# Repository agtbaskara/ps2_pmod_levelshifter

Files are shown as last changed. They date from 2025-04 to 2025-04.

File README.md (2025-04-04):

# PS/2 Pmod with Level Shifter

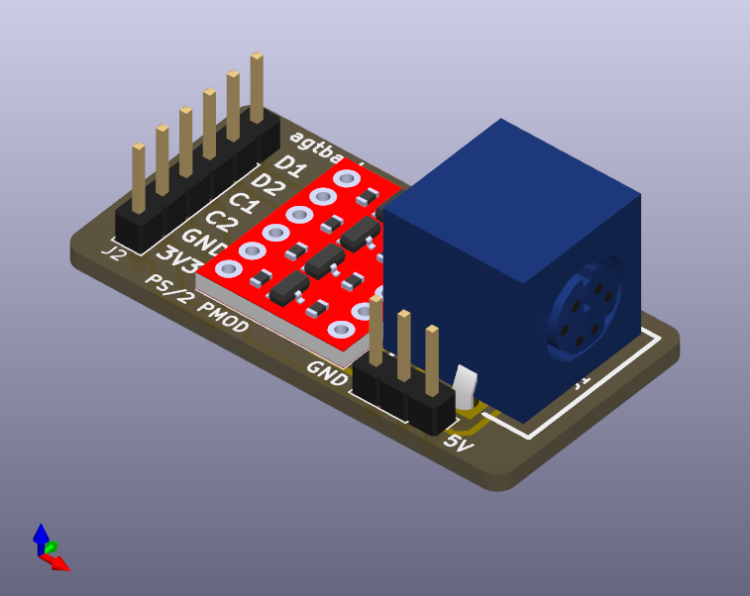
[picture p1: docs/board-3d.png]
Board 3D Render


An Open-Source PS/2 Pmod with Level Shifter to convert the PS/2 signal from 5V to 3.3V.

This board support either 3.3V to 5V step-up converter or external 5V input.

This board intended to use for FPGA projects.

# Schematic

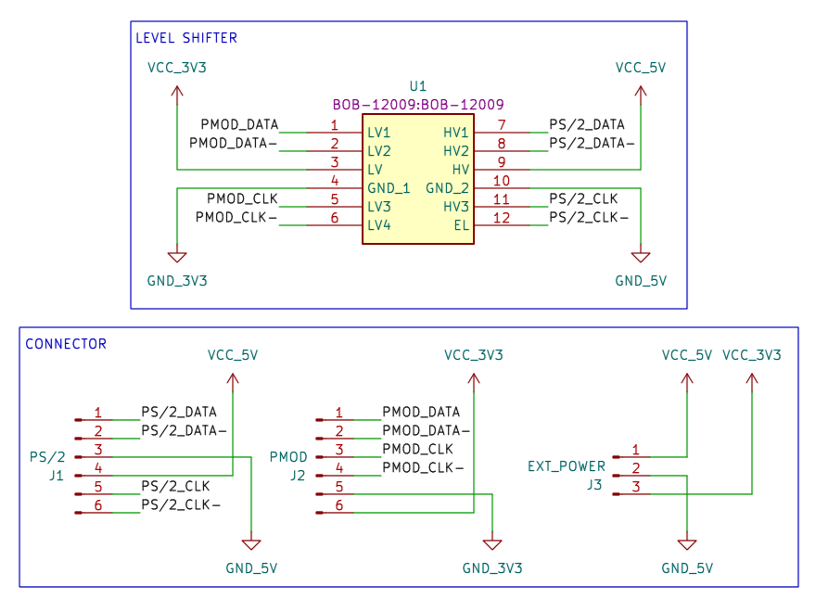
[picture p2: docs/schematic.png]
Schematic


# Required Components

| Reference | Part Number | Description |
|-|-|-|
| U1 | [BOB-12009](https://www.sparkfun.com/products/12009) | Sparkfun Bi-Directional Logic Level Converter, clones are compatible |
| J1 | [PS/2 Connector](https://www.amazon.co.jp/dp/B09HWT37YP) | PS/2 Connector/6-Pin Mini DIN Connector |
| J2 | [Right Angle Pin Header](https://www.amazon.co.jp/dp/B010ESD338) | 1x6 2.54mm Right Angle Male Pin Header |
| J3 | [AE-XC9306-5V0](https://akizukidenshi.com/catalog/g/g115775/) | XC9306 5V Step-up Power Module |

If you want to use external power input instead of step-up converter replace J3 with Pin Header.

| Reference | Part Number | Description |
|-|-|-|
| J3 | [Pin Header](https://www.amazon.co.jp/dp/B017IPWYDK) | 1x2 2.54mm Male Pin Header |

**Attached links are for reference only, you can use any equivalent parts.**

# How to Order Board

To order a board, use the `gerbers.zip` from the release page or generate one yourself. You can order from your favourite PCB manufacturer ([JLCPCB](https://jlcpcb.com/), [PCBWay](https://www.pcbway.com/), etc.).

You can choose any colour for the Solder Mask and Silkscreen.

# How to Use Board

Connect the Pmod to your board, and connect the 5V and GND cable to power source.

# References

- Logic Level Converter (BOB-12009) Footprint: https://www.snapeda.com/parts/BOB-12009/SparkFun%20Electronics/view-part/
- PS/2 Connector (Mini-DIN 6 Pins) Footprint: https://www.reniemarquet.com/bibliotecas_en.html
- Digilent Pmod PS2: https://digilent.com/reference/pmod/pmodps2/start
- Akizuki Denshi XC9306 5V Step-up Modules: https://cba.sakura.ne.jp/kit01/kit_h40.htm

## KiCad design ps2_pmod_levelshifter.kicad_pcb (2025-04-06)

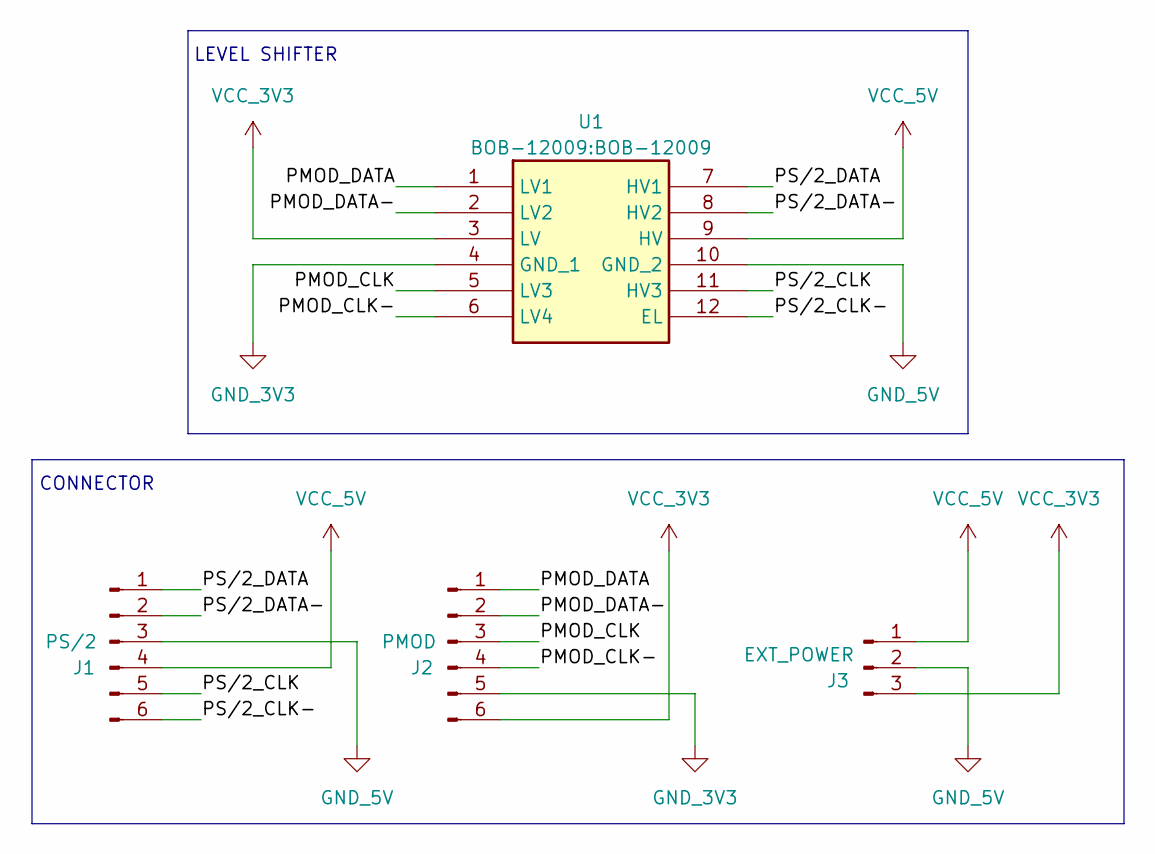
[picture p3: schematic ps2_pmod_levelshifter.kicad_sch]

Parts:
J1: PS/2; ps2_mini_din6
J2: PMOD; PinHeader_1x06_P2.54mm_Vertical
J3: EXT_POWER; PinHeader_1x03_P2.54mm_Vertical
U1: BOB-12009

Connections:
/PMOD_CLK: J2.3, U1.5 (LV3)
/PMOD_CLK-: J2.4, U1.6 (LV4)
/PMOD_DATA: J2.1, U1.1 (LV1)
/PMOD_DATA-: J2.2, U1.2 (LV2)
/PS/2_CLK: J1.5, U1.11 (HV3)
/PS/2_CLK-: J1.6, U1.12 (EL)
/PS/2_DATA: J1.1, U1.7 (HV1)
/PS/2_DATA-: J1.2, U1.8 (HV2)
GND_3V3: J2.5, U1.4 (GND_1)
GND_5V: J1.3, J3.2, U1.10 (GND_2)
VCC_3V3: J2.6, J3.3, U1.3 (LV)
VCC_5V: J1.4, J3.1, U1.9 (HV)

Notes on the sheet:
LEVEL SHIFTER
CONNECTOR

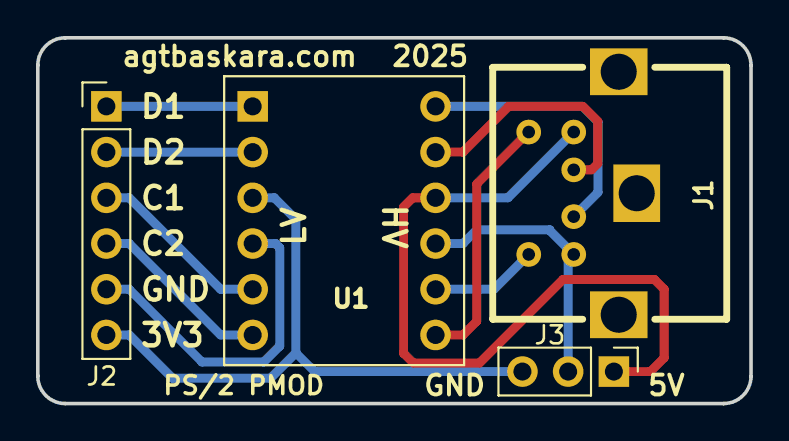
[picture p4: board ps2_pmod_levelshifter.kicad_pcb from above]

Board: 2 copper layers, 39.6 x 20.3 mm, 4 parts (0 on the bottom side), 12 nets.

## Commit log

2025-04-02 add initial design
    [ps2_pmod_levelshifter.kicad_pcb, ps2_pmod_levelshifter.kicad_sch]
2025-04-03 update design
    [ps2_pmod_levelshifter.kicad_pcb, ps2_pmod_levelshifter.kicad_sch]
2025-04-03 update pcb
    [ps2_pmod_levelshifter.kicad_pcb]
